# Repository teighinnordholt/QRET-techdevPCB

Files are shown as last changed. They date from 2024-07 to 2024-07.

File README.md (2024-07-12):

# QRET 2024 Tech Dev Motor Control PCB

## Overview

A simple two-layer PCB designed in KiCAD to control two stepper motors with an Arduino Nano. Designed to clean up the electronics for our 2-axis rocket tracking robot.

## Features

* 4S LiPo input with reverse polarity protection
* Voltage regulation, +BATT and 24V networks
* Battery status indicators
* Modular design with easy access to additional analog/digial/power pins

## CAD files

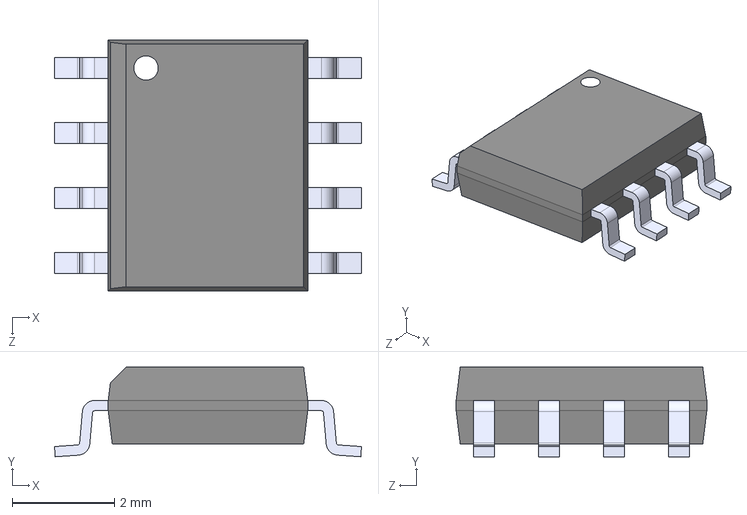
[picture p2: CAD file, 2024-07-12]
PCB/Models/AO4485.step
6.00 x 1.75 x 4.90 mm

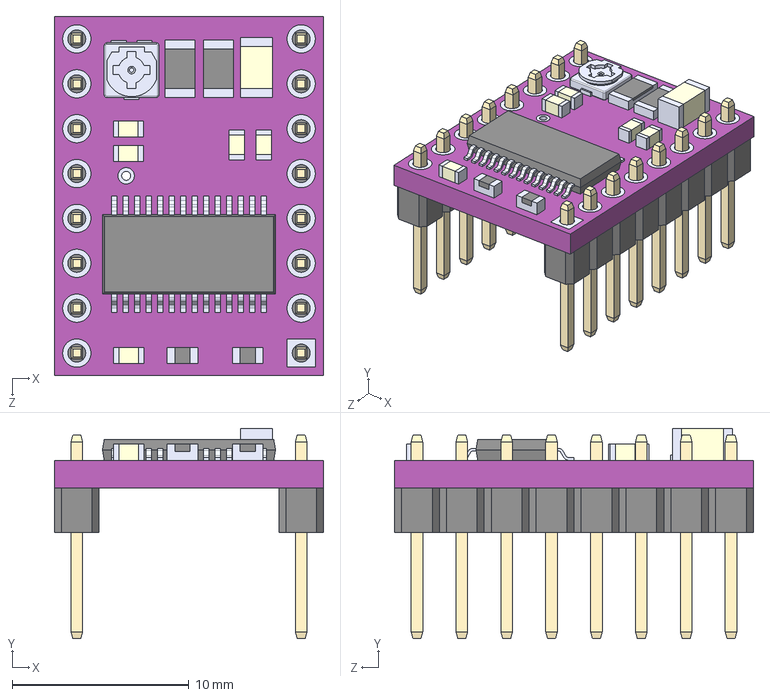
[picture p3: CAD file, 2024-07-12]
PCB/Models/DRV8825_STEPPER_MOTOR_DRIVER_CARRIER.step
15.2 x 11.9 x 20.3 mm

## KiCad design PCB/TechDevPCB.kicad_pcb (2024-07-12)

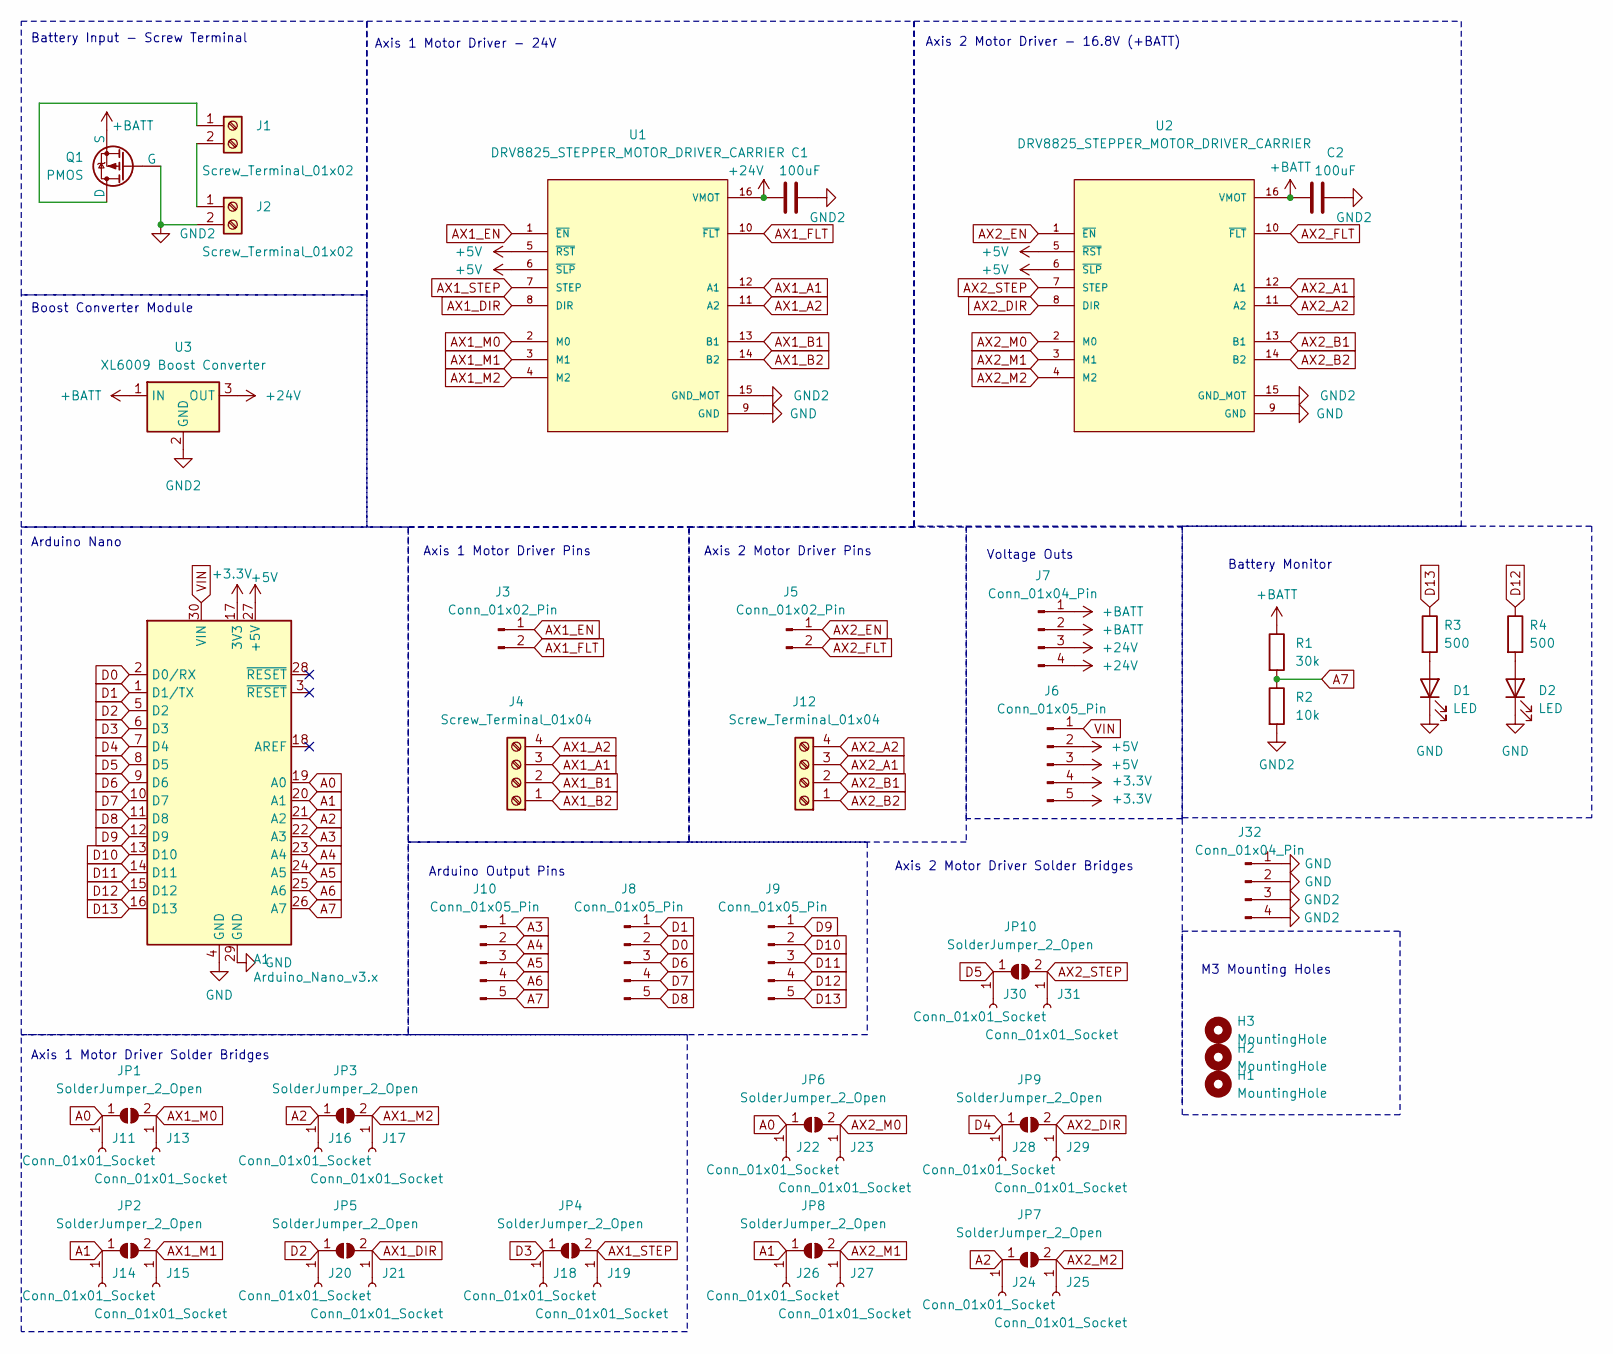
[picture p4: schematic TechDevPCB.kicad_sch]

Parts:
A1: Arduino_Nano_v3.x; Arduino_Nano
C1, C2: 100uF; C_Radial_D5.0mm_H5.0mm_P2.00mm
D1, D2: LED; LED_Rectangular_W3.0mm_H2.0mm
H1, H2, H3: MountingHole; MountingHole_3.2mm_M3_DIN965
J1, J2: Screw_Terminal_01x02; TerminalBlock_bornier-2_P5.08mm
J3, J5: Conn_01x02_Pin; PinHeader_1x02_P2.54mm_Vertical
J4, J12: Screw_Terminal_01x04; TerminalBlock_bornier-4_P5.08mm
J6, J8, J9, J10: Conn_01x05_Pin; PinHeader_1x05_P2.54mm_Vertical
J7, J32: Conn_01x04_Pin; PinHeader_1x04_P2.54mm_Vertical
J11, J13, J14, J15, J16, J17, J18, J19, J20, J21, J22, J23, J24, J25, J26, J27, J28, J29, J30, J31: Conn_01x01_Socket; PinHeader_1x01_P2.54mm_Vertical
JP1, JP2, JP3, JP4, JP5, JP6, JP7, JP8, JP9, JP10: SolderJumper_2_Open; SolderJumper-2_P1.3mm_Open_Pad1.0x1.5mm
Q1: PMOS; TO-251-3-1EP_Horizontal_TabDown
R1: 30k; R_Axial_DIN0207_L6.3mm_D2.5mm_P10.16mm_Horizontal
R2: 10k; R_Axial_DIN0207_L6.3mm_D2.5mm_P10.16mm_Horizontal
R3, R4: 500; R_Axial_DIN0207_L6.3mm_D2.5mm_P10.16mm_Horizontal
U1, U2: DRV8825_STEPPER_MOTOR_DRIVER_CARRIER; IC_DRV8825_STEPPER_MOTOR_DRIVER_CARRIER
U3: XL6009 Boost Converter

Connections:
+3.3V: A1.17 (3V3), J6.4, J6.5
+5V: A1.27 (+5V), J6.2, J6.3, U1.5 (~RST), U1.6 (~SLP), U2.5 (~RST), U2.6 (~SLP)
+24V: C1.1, J7.3, J7.4, U1.16 (VMOT), U3.3 (OUT)
+BATT: C2.1, J7.1, J7.2, Q1.3 (S), R1.1, U2.16 (VMOT), U3.1 (IN)
A0: A1.19 (A0), J11.1, J22.1, JP1.1 (A), JP6.1 (A)
A1: A1.20 (A1), J14.1, J26.1, JP2.1 (A), JP8.1 (A)
A2: A1.21 (A2), J16.1, J24.1, JP3.1 (A), JP7.1 (A)
A3: A1.22 (A3), J10.1
A4: A1.23 (A4), J10.2
A5: A1.24 (A5), J10.3
A6: A1.25 (A6), J10.4
A7: A1.26 (A7), J10.5, R1.2, R2.1
AX1_A1: J4.3, U1.12 (A1)
AX1_A2: J4.4, U1.11 (A2)
AX1_B1: J4.2, U1.13 (B1)
AX1_B2: J4.1, U1.14 (B2)
AX1_DIR: J21.1, JP5.2 (B), U1.8 (DIR)
AX1_EN: J3.1, U1.1 (~EN)
AX1_FLT: J3.2, U1.10 (~FLT)
AX1_M0: J13.1, JP1.2 (B), U1.2 (M0)
AX1_M1: J15.1, JP2.2 (B), U1.3 (M1)
AX1_M2: J17.1, JP3.2 (B), U1.4 (M2)
AX1_STEP: J19.1, JP4.2 (B), U1.7 (STEP)
AX2_A1: J12.3, U2.12 (A1)
AX2_A2: J12.4, U2.11 (A2)
AX2_B1: J12.2, U2.13 (B1)
AX2_B2: J12.1, U2.14 (B2)
AX2_DIR: J29.1, JP9.2 (B), U2.8 (DIR)
AX2_EN: J5.1, U2.1 (~EN)
AX2_FLT: J5.2, U2.10 (~FLT)
AX2_M0: J23.1, JP6.2 (B), U2.2 (M0)
AX2_M1: J27.1, JP8.2 (B), U2.3 (M1)
AX2_M2: J25.1, JP7.2 (B), U2.4 (M2)
AX2_STEP: J31.1, JP10.2 (B), U2.7 (STEP)
D0: A1.2 (D0/RX), J8.2
D1: A1.1 (D1/TX), J8.1
D2: A1.5 (D2), J20.1, JP5.1 (A)
D3: A1.6 (D3), J18.1, JP4.1 (A)
D4: A1.7 (D4), J28.1, JP9.1 (A)
D5: A1.8 (D5), J30.1, JP10.1 (A)
D6: A1.9 (D6), J8.3
D7: A1.10 (D7), J8.4
D8: A1.11 (D8), J8.5
D9: A1.12 (D9), J9.1
D10: A1.13 (D10), J9.2
D11: A1.14 (D11), J9.3
D12: A1.15 (D12), J9.4, R4.1
D13: A1.16 (D13), J9.5, R3.1
GND: A1.4 (GND), A1.29 (GND), D1.1 (K), D2.1 (K), J32.1, J32.2, U1.9 (GND), U2.9 (GND)
GND2: C1.2, C2.2, J2.2, J32.3, J32.4, Q1.2 (G), R2.2, U1.15 (GND_MOT), U2.15 (GND_MOT), U3.2 (GND)
unnamed: D1.2 (A), R3.2
unnamed: D2.2 (A), R4.2
unnamed: J1.1, Q1.1 (D)
unnamed: J1.2, J2.1
VIN: A1.30 (VIN), J6.1

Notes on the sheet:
Boost Converter Module
Axis 2 Motor Driver Pins
Axis 1 Motor Driver Pins
Axis 1 Motor Driver Solder Bridges
Arduino Nano
Battery Input - Screw Terminal
Axis 1 Motor Driver - 24V
Arduino Output Pins
Battery Monitor
M3 Mounting Holes
Axis 2 Motor Driver - 16.8V (+BATT)
Axis 2 Motor Driver Solder Bridges
Voltage Outs

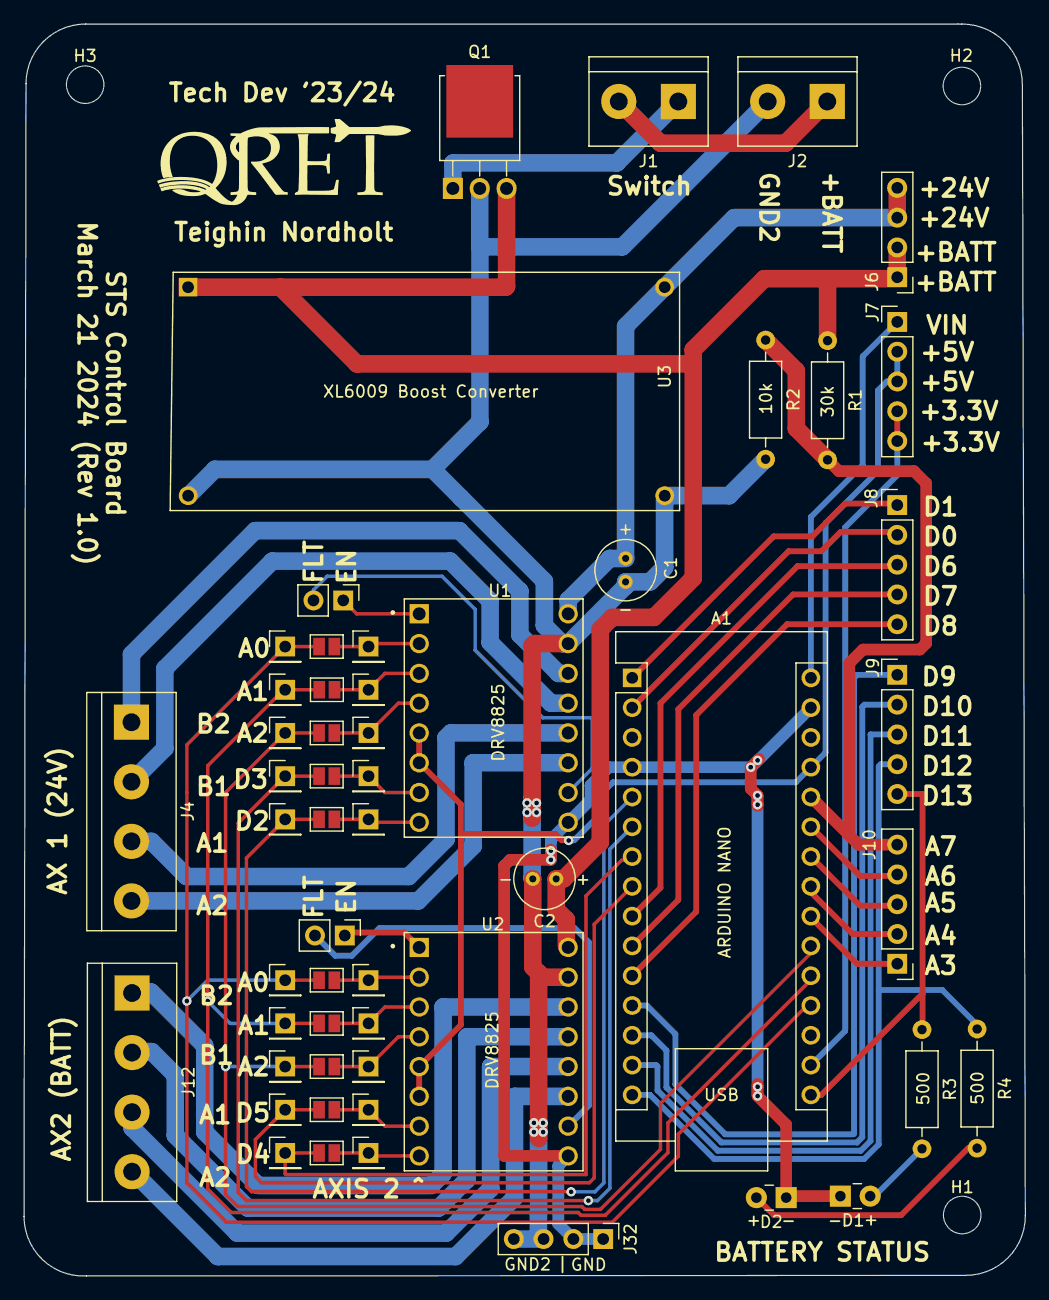
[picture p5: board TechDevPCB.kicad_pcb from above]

Board: 2 copper layers, 85.4 x 106.8 mm, 58 parts (0 on the bottom side), 55 nets.

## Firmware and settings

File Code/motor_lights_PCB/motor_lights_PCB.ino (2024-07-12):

#include <AccelStepper.h>

// Motor 1 Connections
const int dirPin = 2;
const int stepPin = 3;

// Motor 2 Connections
const int dirPin2 = 4;
const int stepPin2 = 5;

// two stepper motors
AccelStepper myStepper1(AccelStepper::DRIVER, stepPin, dirPin);
AccelStepper myStepper2(AccelStepper::DRIVER, stepPin2, dirPin2);

//initializing led pins
const int redLED = 13;
const int greenLED = 12;

bool LEDStates;

//initializing analog pin to read battery voltage
const int readBatt = A7;
float battVolt = 0;

//timer variables to flash leds without interupting
unsigned long prevMills = 0;

void setup() {
  Serial.println("Starting");
  // Motor 1 Configuration
  myStepper1.setMaxSpeed(13000); // Set max speed
  myStepper1.setSpeed(0);    // Set initial speed
  
  // Motor 2 Configuration
  myStepper2.setMaxSpeed(13000); //max speed
  myStepper2.setSpeed(0);    // initial speed
  
  // Microstepping pins configuration
  pinMode(A0, OUTPUT);
  pinMode(A1, OUTPUT);
  pinMode(A2, OUTPUT);

  // Microstepping for 1/32
  digitalWrite(A0, HIGH);
  digitalWrite(A1, HIGH);
  digitalWrite(A2, HIGH);

  pinMode(redLED, OUTPUT);
  pinMode(greenLED, OUTPUT);

  Serial.begin(115200);
  Serial.println("Setup successful");
}

void loop() {

  //read battery voltage
  battVolt = (5*((float)analogRead(readBatt))/1024)*4;
  Serial.println(battVolt);

  //updating time
  unsigned long currMills = millis();

  //if a second has passed
  if(currMills - prevMills >= 1000){
    prevMills = currMills;
    LEDStates = !LEDStates;
    if(battVolt > 15){
      digitalWrite(greenLED, LEDStates);
      digitalWrite(redLED, 0);
    }else{
      digitalWrite(redLED, LEDStates);
      digitalWrite(greenLED, 0);
    }
  }
  
  if (Serial.available() > 0) {
    // Expecting input format: speed1 speed2
    float speed1 = Serial.parseFloat(); // Reads the first speed until it encounters a non-integer character
    float speed2 = Serial.parseFloat(); // Reads the next integer after the space
    Serial.print(speed1);
    Serial.println(speed2);
    
    // Apply the speeds to the stepper motors
    if (1) {
      
      speed1 = -1*(speed1/360)*6400;
      speed2 = (speed2/360)*6400;
      
      myStepper1.setSpeed(speed1);
      Serial.print("Speed1: ");
      Serial.print(speed1 + String(" | "));
      myStepper2.setSpeed(speed2);
      Serial.print(" Speed2: ");
      Serial.println(speed2);
    } else {
      Serial.println("Invalid input. Enter positive numbers separated by a space.");
    }

    // Clear the serial buffer by reading until newline or timeout
    while (Serial.available() > 0) {
      char c = Serial.read();
      if (c == '\n' || c == '\r') break;
    }
  }
  myStepper1.runSpeed();
  myStepper2.runSpeed();
}

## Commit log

2024-07-12 initial commit from tech dev repo
    [AO4485.step, DRV8825_STEPPER_MOTOR_DRIVER_CARRIER.step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]
2024-07-12 added arduino script for lights and motor control
    [TechDevPCB-B_Cu.gbr, TechDevPCB-B_Mask.gbr, TechDevPCB-B_Paste.gbr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]
